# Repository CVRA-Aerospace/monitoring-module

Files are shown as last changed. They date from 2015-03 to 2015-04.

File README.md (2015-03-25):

Rocket monitoring module
========================
This is a compact monitoring system.
It is used for monitoring a rocket.

Main features:
-------------
 - 3-axis gyroscope
 - Two 3-axis accelerometers (one for low g and one for high g accelerations)
 - 3-axis magnetometer
 - Barometer
 - ARM controller
 - microSD card
 - 1x CAN
 - 1x UART

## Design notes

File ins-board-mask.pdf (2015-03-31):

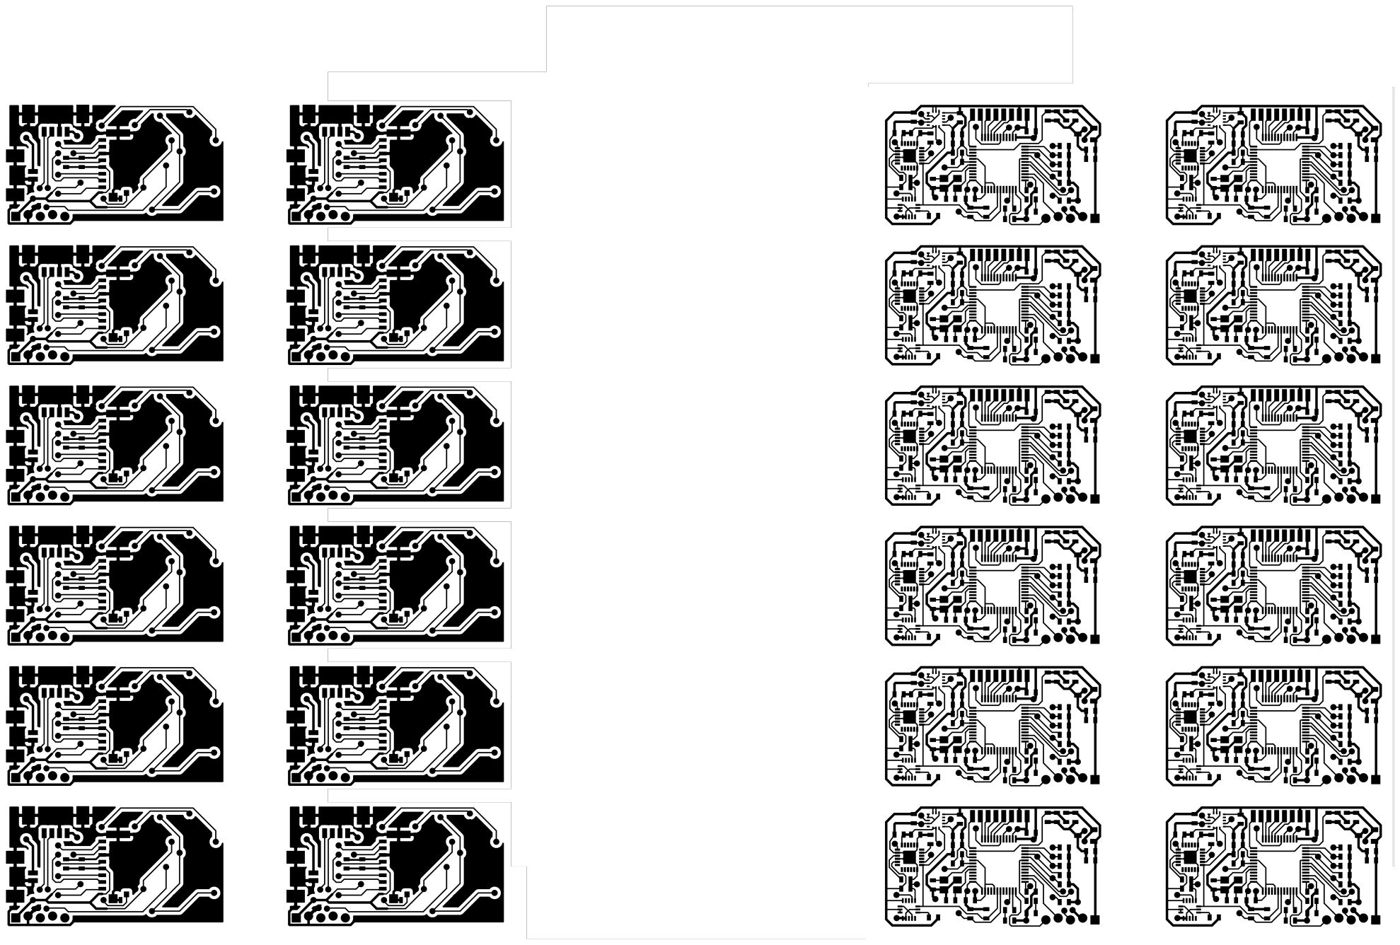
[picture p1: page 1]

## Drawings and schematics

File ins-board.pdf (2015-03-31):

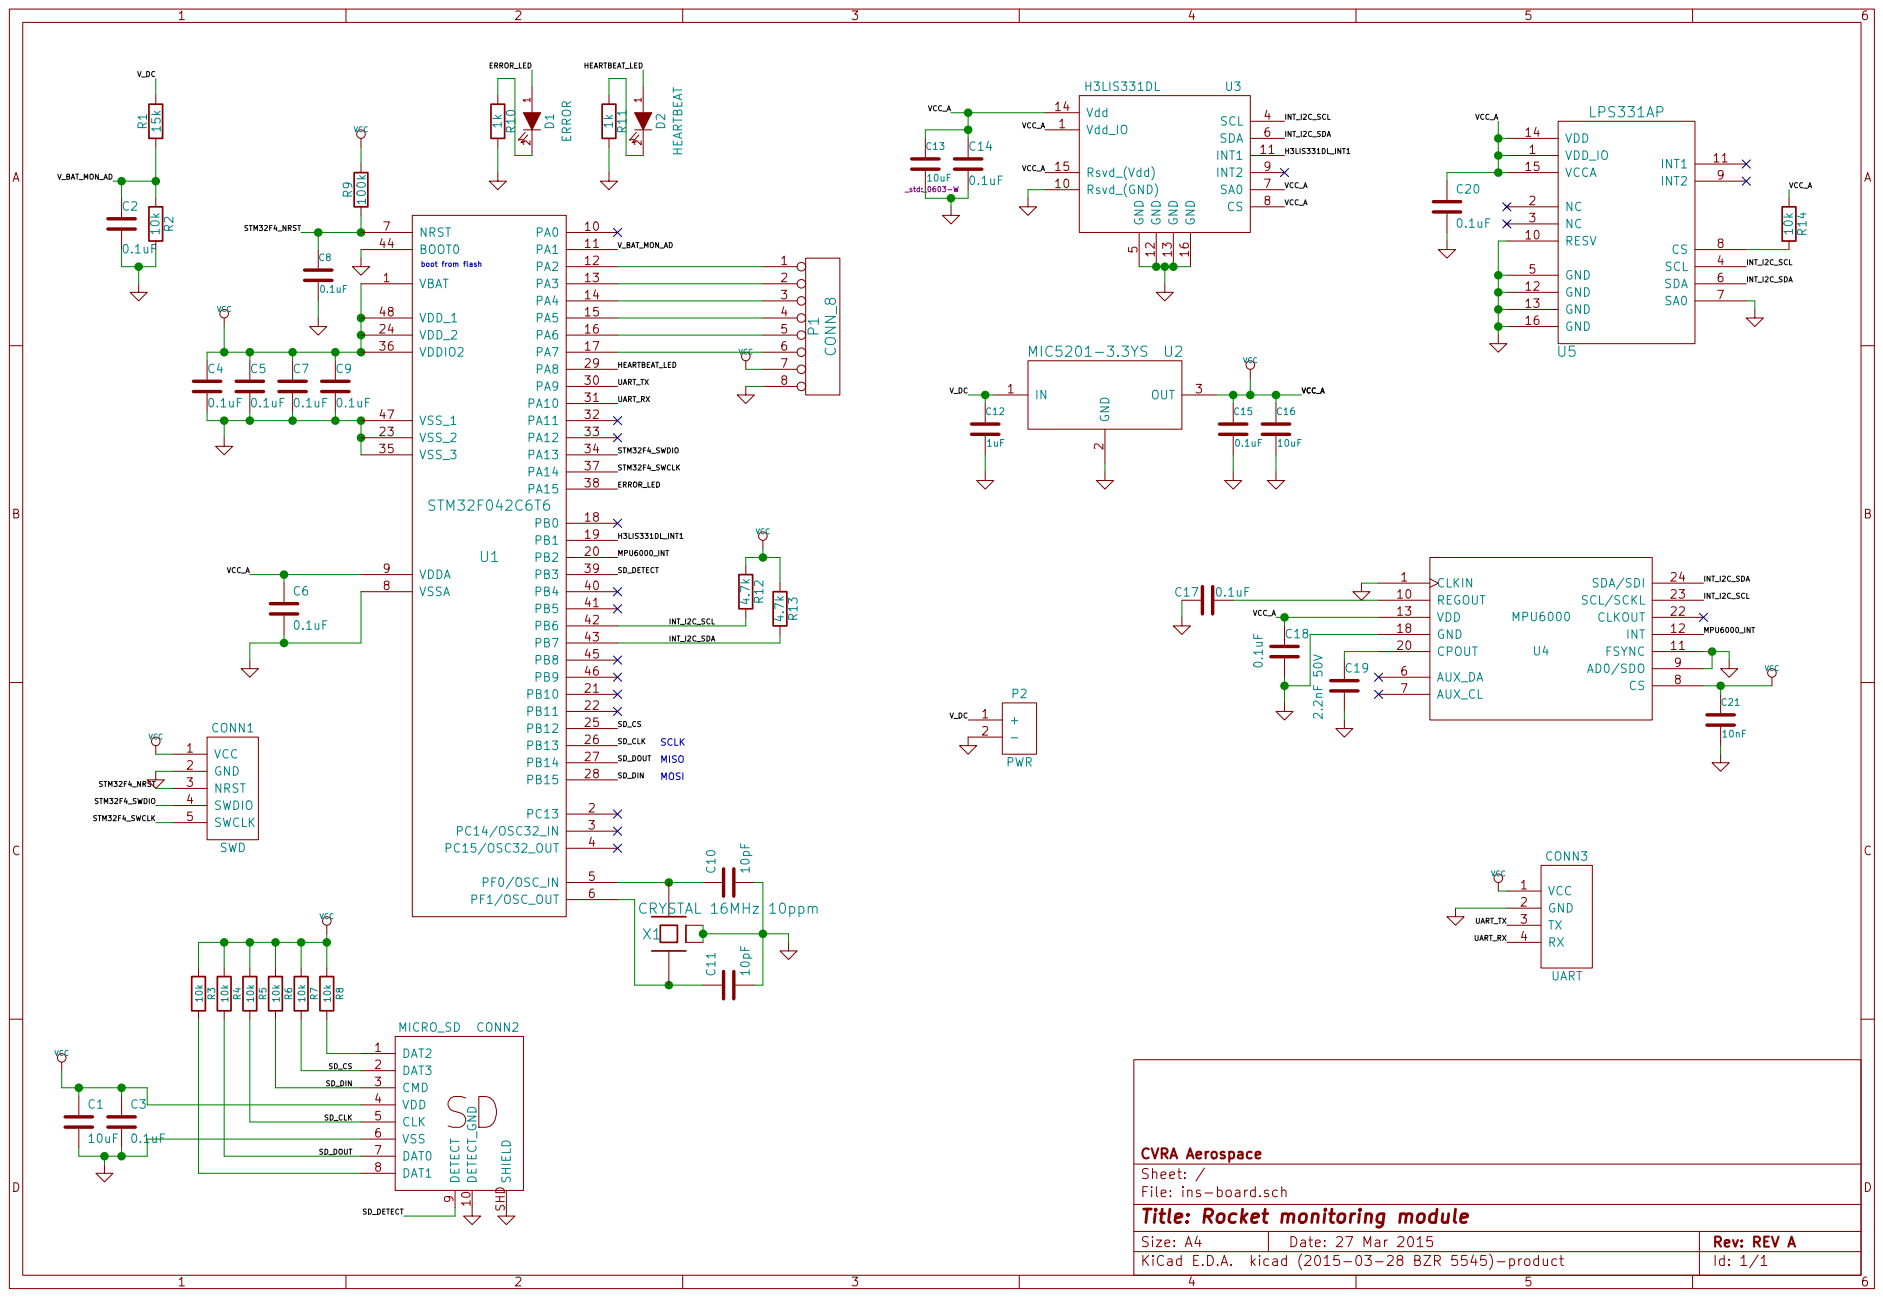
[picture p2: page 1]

boot from flash VCC R9 100k

File: ins-board.sch Sheet: / CVRA Aerospace 4.7k R134.7k R12

Id: 1/1 Title: Rocket monitoring module

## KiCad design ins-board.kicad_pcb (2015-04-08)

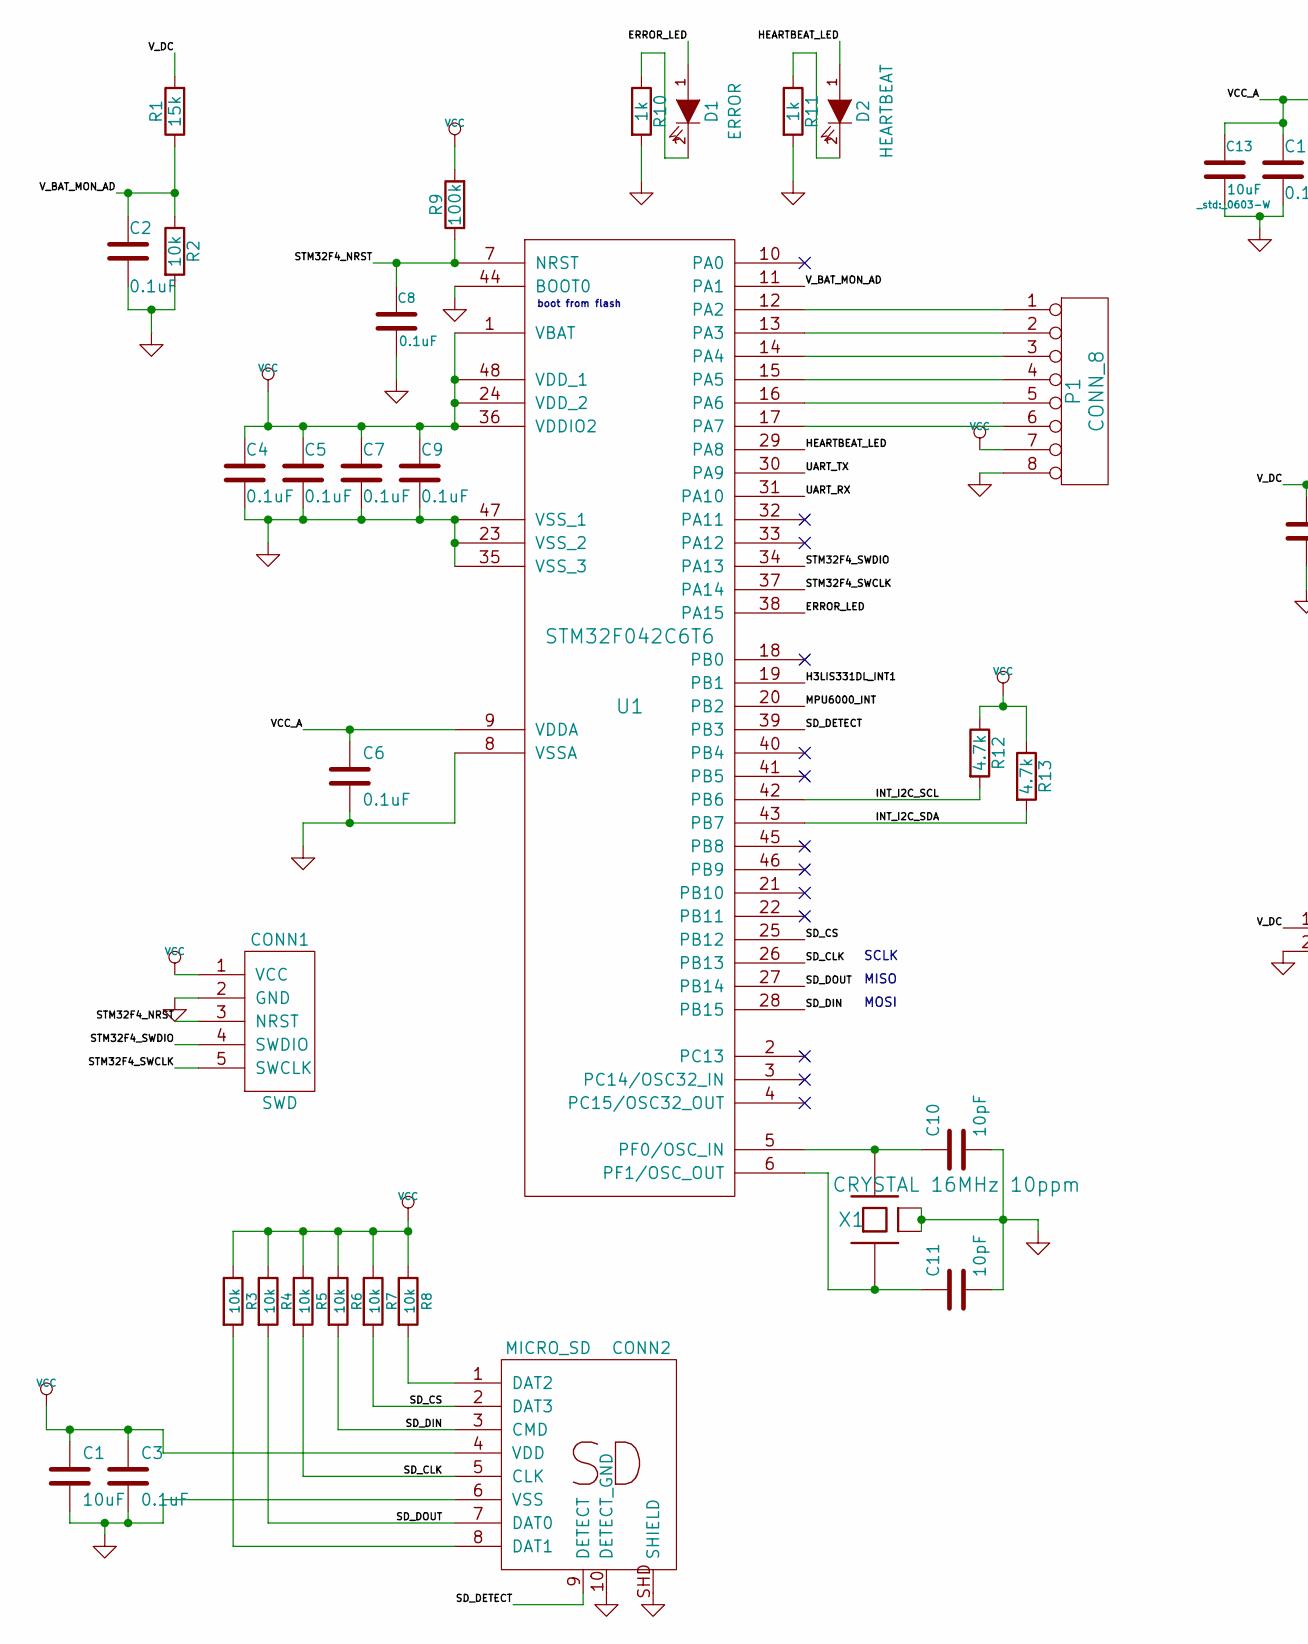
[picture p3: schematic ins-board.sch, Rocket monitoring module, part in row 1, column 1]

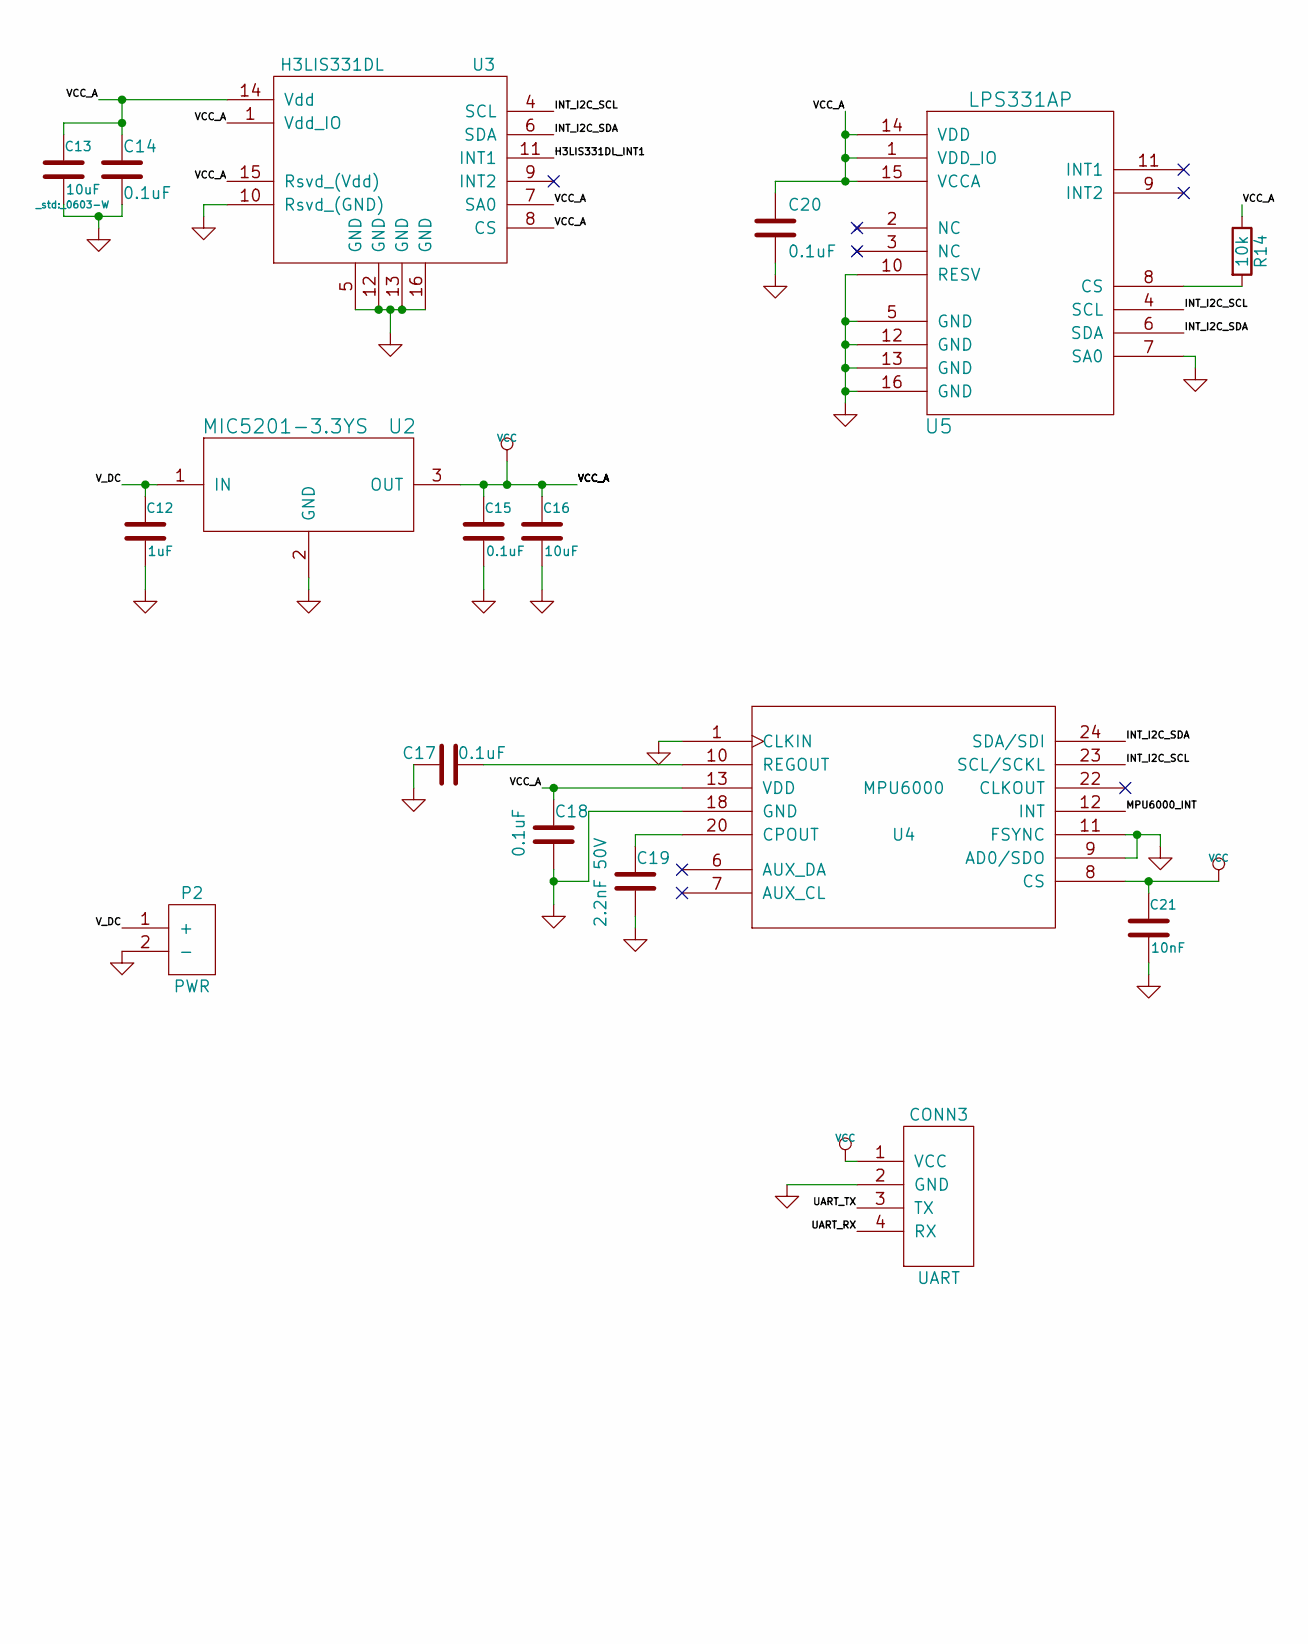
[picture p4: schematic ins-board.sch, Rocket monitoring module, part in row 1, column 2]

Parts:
C1, C13, C16: 10uF; _0603-W
C2, C3, C4, C5, C6, C7, C8, C9, C14, C15, C17, C18, C20: 0.1uF; _0603-W
C10, C11: 10pF; _0603-W
C12: 1uF; _0603-W
C19: 2.2nF 50V; _0603-W
C21: 10nF; _0603-W
CONN1: SWD; _Pin2mm_5z
CONN2: MICRO_SD; _Molex-microSD-502570-0893
CONN3: UART; _Molex-PicoBlade-SMD-4
D1: ERROR; _0603-W
D2: HEARTBEAT; _0603-W
P1: CONN_8; _Solder_Pad1.27_8
P2: PWR; _Molex-PicoBlade-SMD-2
R1: 15k; _0603-W
R2, R3, R4, R5, R6, R7, R8: 10k; _0603-W
R9: 100k; _0603-W
R10, R11: 1k; _0603-W
R12, R13: 4.7k; _0603-W
R14: 10k
U1: STM32F042C6T6; _LQFP48
U2: MIC5201-3.3YS; _SOT23-3
U3: H3LIS331DL; _H3LIS331DL
U4: MPU6000; _MPU-60X0
U5: LPS331AP
X1: CRYSTAL 16MHz 10ppm; _TSX-3225-SMD-XTAL

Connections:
/ERROR_LED: D1.1 (A), U1.38 (PA15)
/H3LIS331DL_INT1: U1.19 (PB1), U3.11 (INT1)
/HEARTBEAT_LED: D2.1 (A), U1.29 (PA8)
/INT_I2C_SCL: R12.2, U1.42 (PB6), U3.4 (SCL), U4.23 (SCL/SCKL), U5.4 (SCL)
/INT_I2C_SDA: R13.2, U1.43 (PB7), U3.6 (SDA), U4.24 (SDA/SDI), U5.6 (SDA)
/MPU6000_INT: U1.20 (PB2), U4.12 (INT)
/SD_CLK: CONN2.5 (CLK), R5.2, U1.26 (PB13)
/SD_CS: CONN2.2 (DAT3), R7.2, U1.25 (PB12)
/SD_DETECT: CONN2.9 (DETECT), U1.39 (PB3)
/SD_DIN: CONN2.3 (CMD), R6.2, U1.28 (PB15)
/SD_DOUT: CONN2.7 (DAT0), R4.2, U1.27 (PB14)
/STM32F4_NRST: C8.1, CONN1.3 (NRST), R9.1, U1.7 (NRST)
/STM32F4_SWCLK: CONN1.5 (SWCLK), U1.37 (PA14)
/STM32F4_SWDIO: CONN1.4 (SWDIO), U1.34 (PA13)
/UART_RX: CONN3.4 (RX), U1.31 (PA10)
/UART_TX: CONN3.3 (TX), U1.30 (PA9)
/V_BAT_MON_AD: C2.1, R1.1, R2.1, U1.11 (PA1)
/V_DC: C12.1, P2.1 (+), R1.2, U2.1 (IN)
GND: C1.2, C2.2, C3.2, C4.2, C5.2, C6.2, C7.2, C8.2, C9.2, C10.2, C11.2, C12.2, C13.2, C14.2, C15.2, C16.2, C17.1, C18.2, C19.2, C20.2, C21.2, CONN1.2 (GND), CONN2.6 (VSS), CONN2.10 (DETECT_GND), CONN2.SHD (SHIELD), CONN3.2 (GND), CONN3.MECH (GND), P1.8, P2.2 (-), P2.MECH (GND), R2.2, R10.2, R11.2, U1.8 (VSSA), U1.23 (VSS_2), U1.35 (VSS_3), U1.44 (BOOT0), U1.47 (VSS_1), U2.2 (GND), U3.5 (GND), U3.10 (Rsvd_(GND)), U3.12 (GND), U3.13 (GND), U3.16 (GND), U4.1 (CLKIN), U4.9 (AD0/SDO), U4.11 (FSYNC), U4.18 (GND), U5.5 (GND), U5.7 (SA0), U5.10 (RESV), U5.12 (GND), U5.13 (GND), U5.16 (GND), X1.2 (case), X1.4 (case)
unnamed: C10.1, U1.5 (PF0/OSC_IN), X1.3
unnamed: C11.1, U1.6 (PF1/OSC_OUT), X1.1
unnamed: C17.2, U4.10 (REGOUT)
unnamed: C19.1, U4.20 (CPOUT)
unnamed: CONN2.1 (DAT2), R8.2
unnamed: CONN2.8 (DAT1), R3.2
unnamed: D1.2 (K), R10.1
unnamed: D2.2 (K), R11.1
unnamed: P1.1, U1.12 (PA2)
unnamed: P1.2, U1.13 (PA3)
unnamed: P1.3, U1.14 (PA4)
unnamed: P1.4, U1.15 (PA5)
unnamed: P1.5, U1.16 (PA6)
unnamed: P1.6, U1.17 (PA7)
unnamed: R14.2, U5.8 (CS)
VCC: C1.1, C3.1, C4.1, C5.1, C6.1, C7.1, C9.1, C13.1, C14.1, C15.1, C16.1, C18.1, C20.1, C21.1, CONN1.1 (VCC), CONN2.4 (VDD), CONN3.1 (VCC), P1.7, R3.1, R4.1, R5.1, R6.1, R7.1, R8.1, R9.2, R12.1, R13.1, R14.1, U1.1 (VBAT), U1.9 (VDDA), U1.24 (VDD_2), U1.36 (VDDIO2), U1.48 (VDD_1), U2.3 (OUT), U3.1 (Vdd_IO), U3.7 (SA0), U3.8 (CS), U3.14 (Vdd), U3.15 (Rsvd_(Vdd)), U4.8 (CS), U4.13 (VDD), U5.1 (VDD_IO), U5.14 (VDD), U5.15 (VCCA)

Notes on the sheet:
boot from flash
SCLK
MOSI
MISO

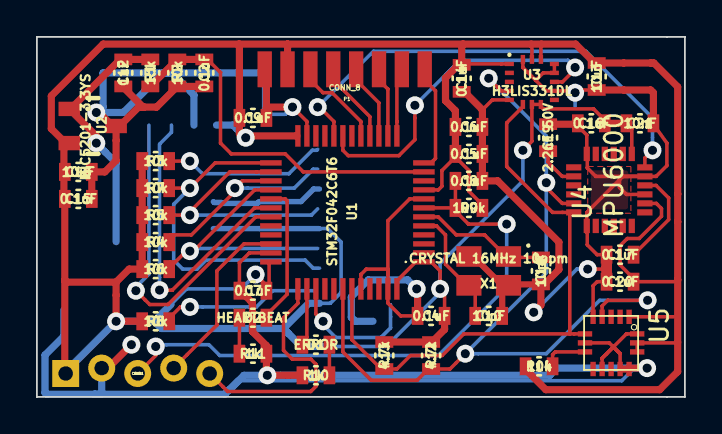
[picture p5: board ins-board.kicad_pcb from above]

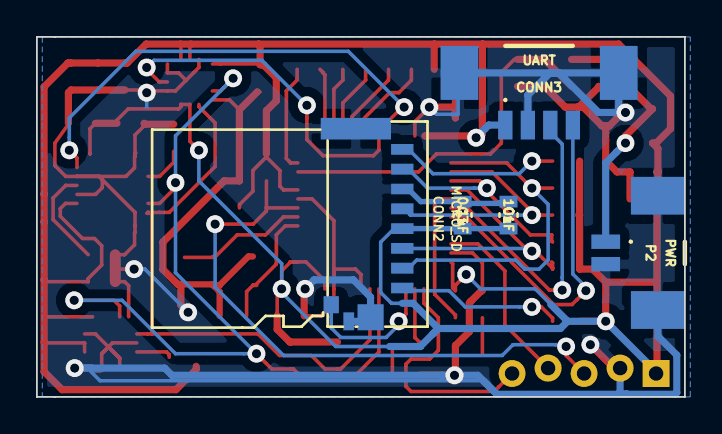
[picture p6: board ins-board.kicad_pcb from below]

Board: 2 copper layers, 36.0 x 20.0 mm, 48 parts (5 on the bottom side), 35 nets.

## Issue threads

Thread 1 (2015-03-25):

review

Stapelzeiger, 2015-03-25:

Stapelzeiger, 2015-03-26:
- sdcard: DAT3 -> CS

nuft, 2015-03-26:
Why do you place external pullups at the SPI?

nuft, 2015-03-26:
Is the CAN_EN line really needed?

Stapelzeiger, 2015-03-26:
> Why do you place external pullups at the SPI?

To avoid a potential SD card lockup when MCU is in reset.

CAN was removed to simplify PCB routing and reduce cost

Closed 2015-04-08.

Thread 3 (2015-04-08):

Voltage Regulator Footprint

froj, 2015-04-08:
It's a `SOT-223`.

SyrianSpock, 2015-04-08:
Already opened an issue here https://github.com/Stapelzeiger/kicad-lib/issues/1 which seemed more appropriate since the component doesn't exist in SOT23

froj, 2015-04-08:
It's still an issue here because it needs rerouting.

SyrianSpock, 2015-04-09:
Not just that, actually the mistake was the wrong association in the netlist, the error is not coming from the library.

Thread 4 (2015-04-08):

Via too close to SD card connector

froj, 2015-04-08:

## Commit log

2015-03-25 rocket board
    [ins-board-B_Cu.gbl, ins-board-B_Mask.gbs, ins-board-B_SilkS.gbo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]
2015-03-25 Use kicad library fork of CVRA Aerospace
2015-03-25 component values
    [ins-board.sch]
2015-03-26 sd-card fix
    [ins-board.sch]
2015-03-26 remove optional components
    [ins-board.sch]
2015-03-26 pcb + footprints
    [ins-board.kicad_pcb, ins-board.sch]
2015-03-26 new libs
    [ins-board.kicad_pcb]
2015-03-28 Add pressure sensor (sch) & fix drc violations
    [ins-board.sch]
2015-03-28 Generate netlist
    [ins-board.sch]
2015-03-28 Component placement on PCB
    [ins-board.kicad_pcb]
2015-03-28 Correct microSD connector footprint & update component placement
    [ins-board.kicad_pcb]
2015-03-28 update sd-card footprint
    [ins-board.kicad_pcb]
2015-03-29 Replace components to ease routing
    [ins-board.kicad_pcb, ins-board.sch]
2015-03-29 Replace components to ease routing (2)
    [ins-board.kicad_pcb]
2015-03-29 PCB review + corrections
    [ins-board.kicad_pcb]
2015-03-30 Update pdf
    [ins-board.sch]
2015-03-31 mask for PCB manufacturing
2015-04-08 missing Vcc connection
    [ins-board.kicad_pcb]
